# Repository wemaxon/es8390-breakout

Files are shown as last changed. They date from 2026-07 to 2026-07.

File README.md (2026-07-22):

# ES8390 Breakout Board

A KiCad-based ES8390 audio codec breakout board featuring guitar and line inputs, an onboard MEMS microphone, line and amplified stereo speaker outputs.

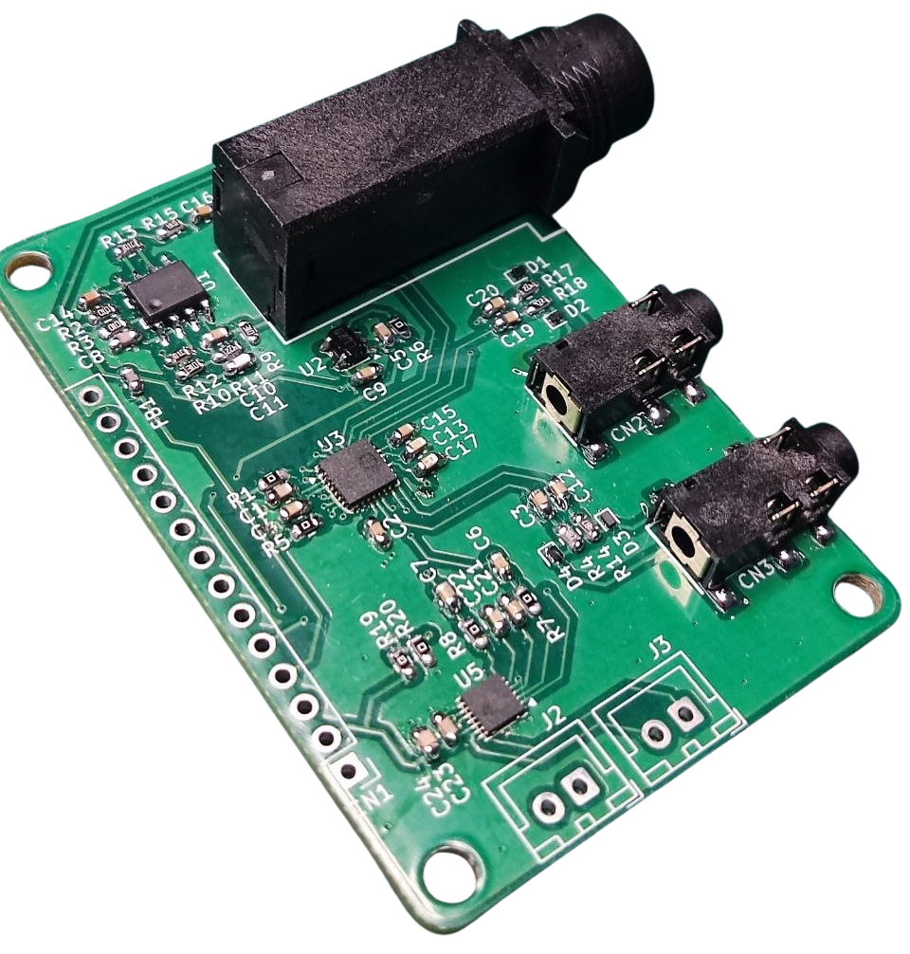
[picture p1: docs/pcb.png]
pcb


Tested Features:
- [x] LP5907 3.0V LDO
- [x] ES8390 Audio-Codec
- [x] Line-Out
- [ ] Line-In
- [x] MAX98306 Class D Stereo Amp
- [ ] TLV9062 Guitar Pre-Amp
- [ ] MSM381ACP003 MEMS Microphone

## Schematic
schematic

## Layout
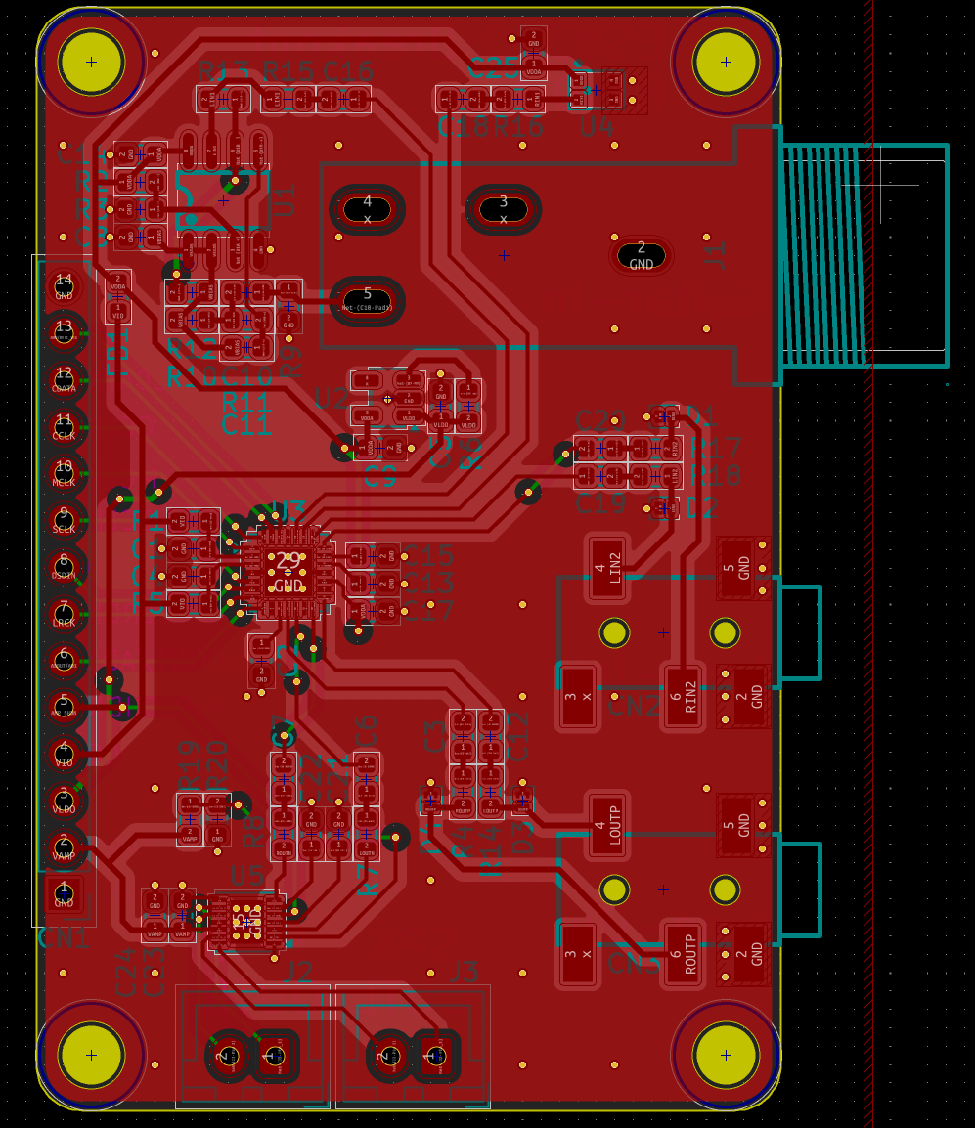
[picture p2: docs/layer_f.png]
layer_f

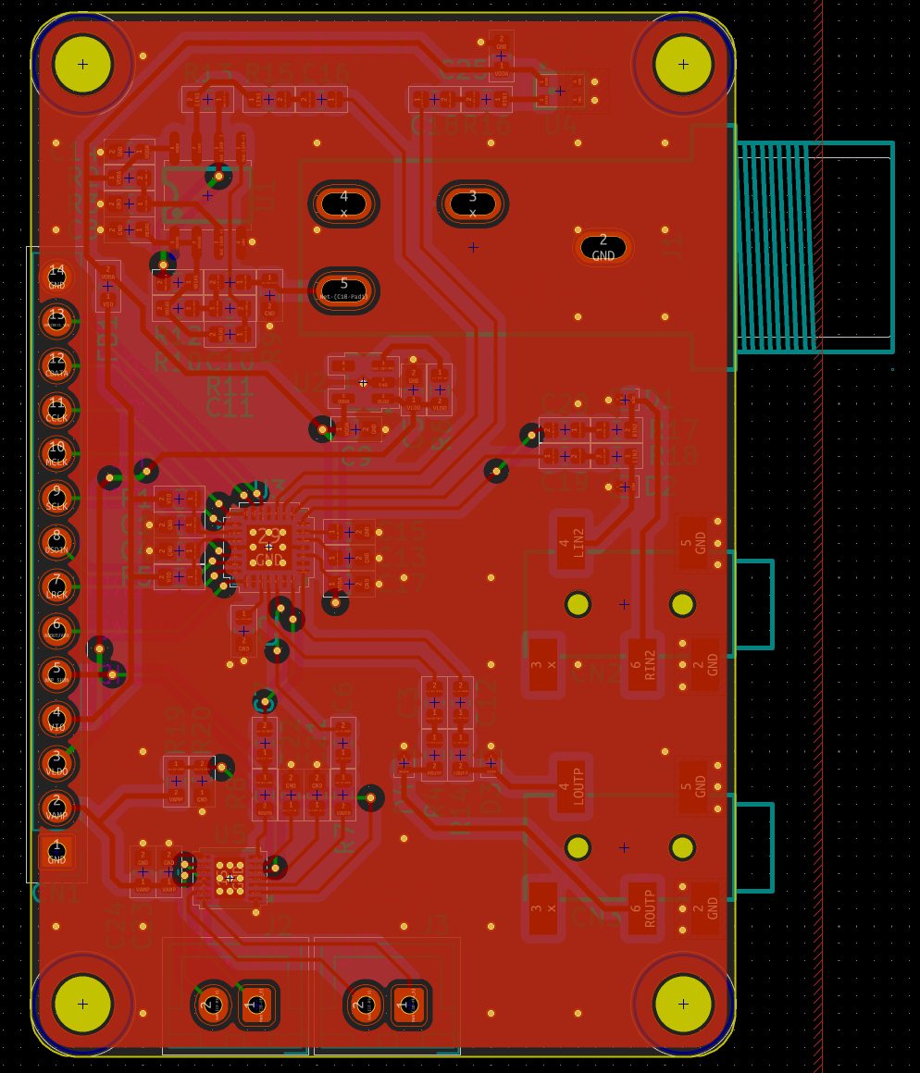
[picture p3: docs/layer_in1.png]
layer_in1

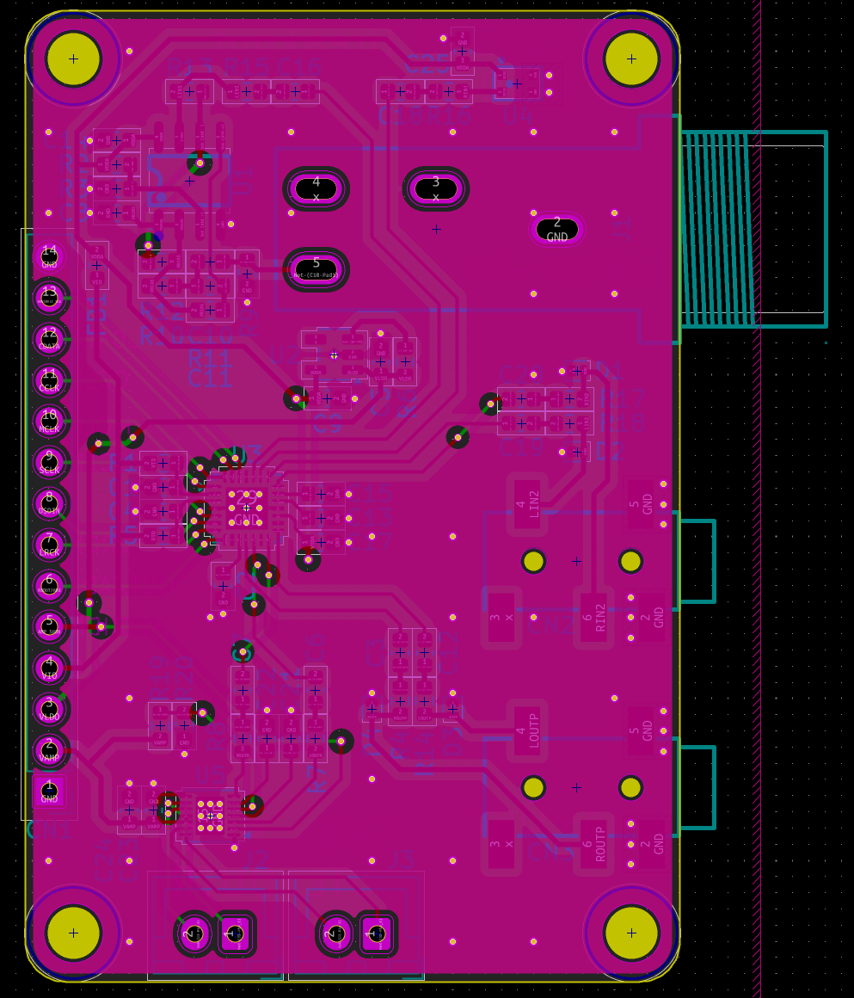
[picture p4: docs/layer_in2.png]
layer_in2

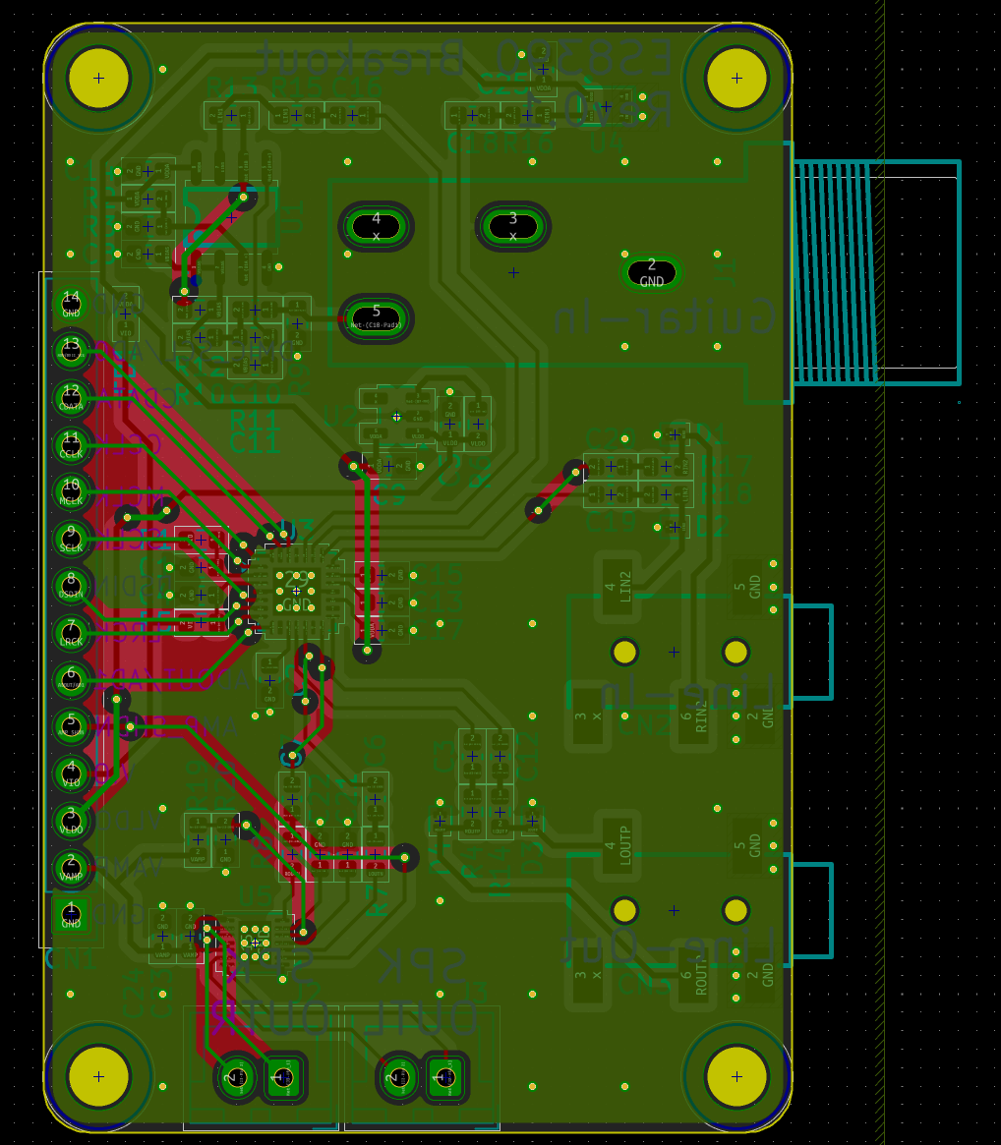
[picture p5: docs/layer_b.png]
layer_b


## Todo
- Fix OUT connections, OUTN to gnd, use output as single ended

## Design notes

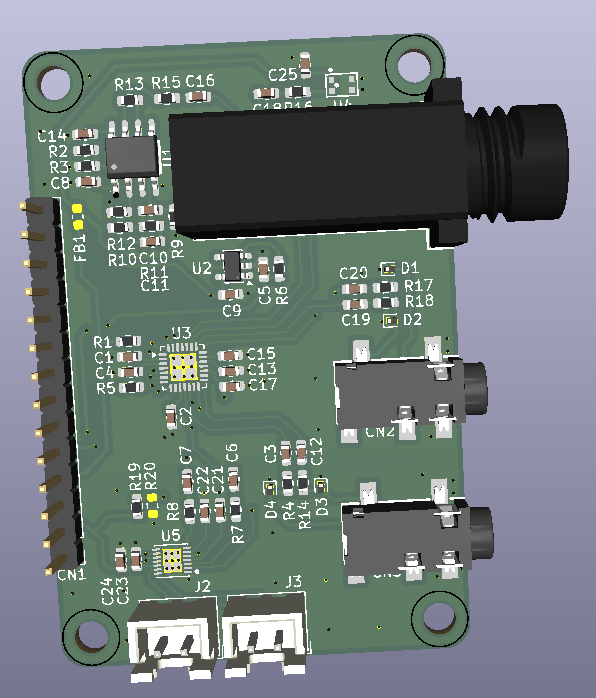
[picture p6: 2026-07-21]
docs/3d.png

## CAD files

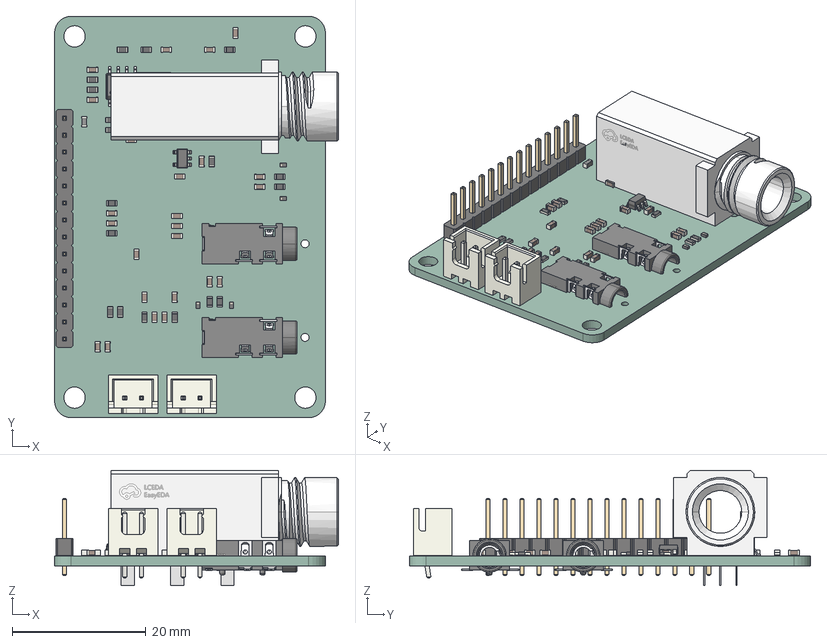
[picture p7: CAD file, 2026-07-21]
es8390-breakout.step
42.5 x 60.0 x 17.2 mm
R_0603_1608Metric x 20
C_0603_1608Metric x 25
JST_XH_B2B-XH-A_1x02_P2.50mm_Vertical x 2
D_SOD-882 x 4
L_0603_1608Metric
AUDIO-SMD_XUNPU_PJ-327A x 2
PinHeader_1x14_P2.54mm_Vertical
SOIC-8_L5.0-W4.0-P1.27-LS6.0-BL
AUDIO-SMD_PJ-603A
SOT-23-5
ES8390-breakout_PCB

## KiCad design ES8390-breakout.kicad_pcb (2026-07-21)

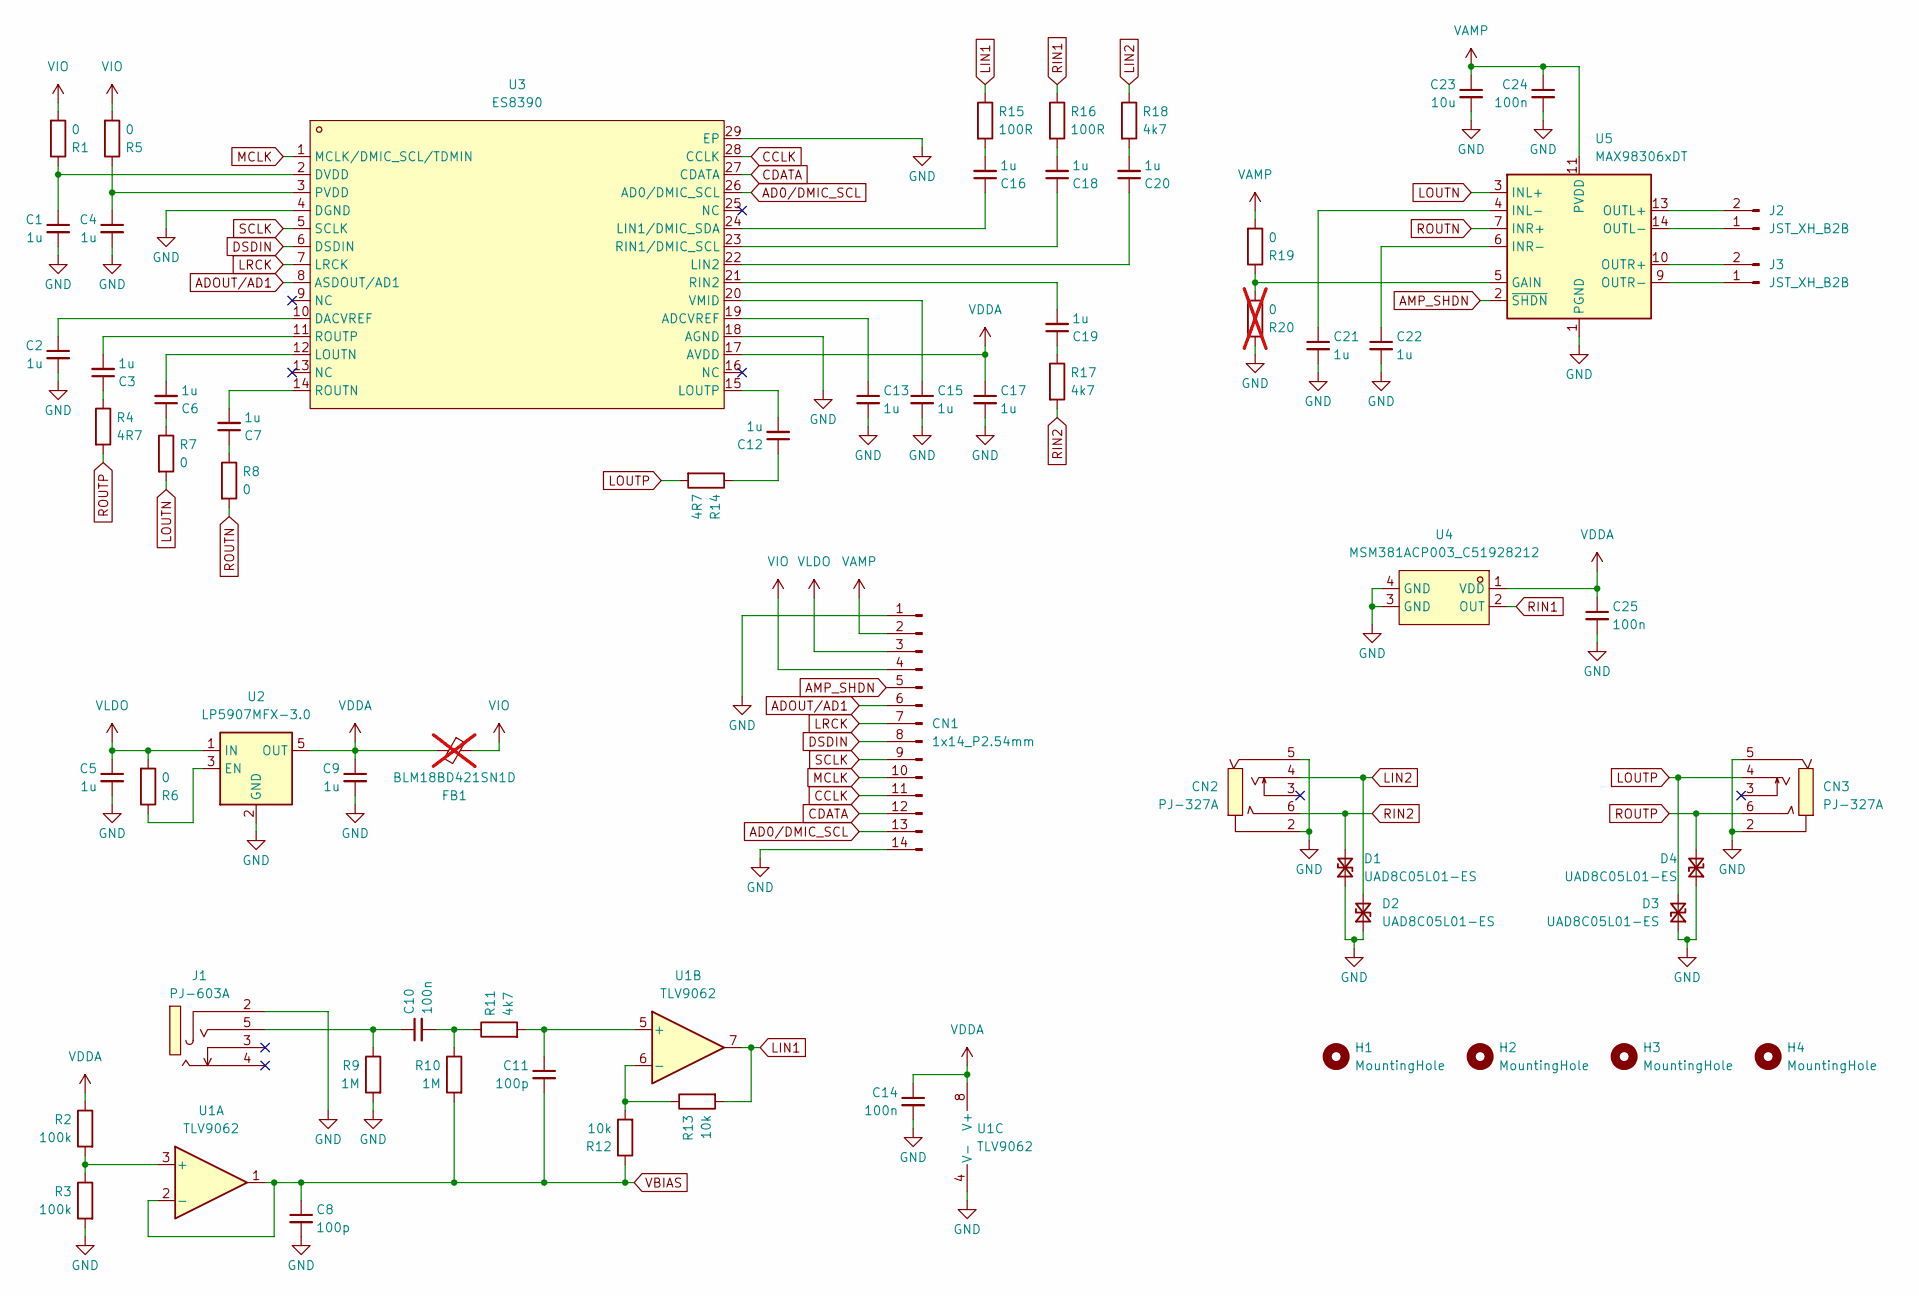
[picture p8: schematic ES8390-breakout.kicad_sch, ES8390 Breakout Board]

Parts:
C1, C2, C3, C4, C5, C6, C7, C9, C12, C13, C15, C16, C17, C18, C19, C20, C21, C22: 1u; C_0603_1608Metric; LCSC Part C15849
C8, C11: 100p; C_0603_1608Metric; LCSC Part C14663
C10, C14, C24, C25: 100n; C_0603_1608Metric; LCSC Part C14663
C23: 10u; C_0603_1608Metric; LCSC Part C96446
CN1: 1x14_P2.54mm; PinHeader_1x14_P2.54mm_Vertical
CN2, CN3: PJ-327A; AUDIO-SMD_XUNPU_PJ-327A; MPN PJ-327A; LCSC Part C49284723
D1, D2, D3, D4: UAD8C05L01-ES; D_SOD-882; LCSC Part C5199205
FB1: BLM18BD421SN1D; L_0603_1608Metric; LCSC Part C113023; not fitted
H1, H2, H3, H4: MountingHole; MountingHole_3.2mm_M3_DIN965
J1: PJ-603A; AUDIO-TH_PJ-603A; MPN PJ-603A; LCSC Part C309273
J2, J3: JST_XH_B2B; JST_XH_B2B-XH-A_1x02_P2.50mm_Vertical
R1, R5, R6, R7, R8, R19: 0; R_0603_1608Metric; LCSC Part C95177
R2, R3: 100k; R_0603_1608Metric; LCSC Part C14675
R4, R14: 4R7; R_0603_1608Metric; LCSC Part C105588
R9, R10: 1M; R_0603_1608Metric; LCSC Part C105578
R11, R17, R18: 4k7; R_0603_1608Metric; LCSC Part C99782
R12, R13: 10k; R_0603_1608Metric; LCSC Part C2906982
R15, R16: 100R; R_0603_1608Metric; LCSC Part C105588
R20: 0; R_0603_1608Metric; LCSC Part C95177; not fitted
U1: TLV9062; SOIC-8_L5.0-W4.0-P1.27-LS6.0-BL; LCSC Part C54539963
U2: LP5907MFX-3.0; SOT-23-5; LCSC Part C23380873
U3: ES8390; QFN-28-1EP_4x4mm_P0.45mm_EP2.6x2.6mm; MPN ES8390; LCSC Part C42405905
U4: MSM381ACP003_C51928212; MIC-SMD_4P-L2.8-W1.9-TR_MSM381ACP003; MPN MSM381ACP003; LCSC Part C51928212
U5: MAX98306xDT; TDFN-14-1EP_3x3mm_P0.4mm_EP1.78x2.35mm; LCSC Part C124549

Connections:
AD0/DMIC_SCL: CN1.13, U3.26 (AD0/DMIC_SCL)
ADOUT/AD1: CN1.6, U3.8 (ASDOUT/AD1)
AMP_SHDN: CN1.5, U5.2 (~SHDN)
CCLK: CN1.11, U3.28 (CCLK)
CDATA: CN1.12, U3.27 (CDATA)
DSDIN: CN1.8, U3.6 (DSDIN)
GND: C1.2, C2.2, C4.2, C5.2, C8.2, C9.2, C13.2, C14.2, C15.2, C17.2, C21.2, C22.2, C23.2, C24.2, C25.2, CN1.1, CN1.14, CN2.2, CN2.5, CN3.2, CN3.5, D1.1 (A1), D2.1 (A1), D3.1 (A1), D4.1 (A1), J1.2, R3.2, R9.2, R20.1, U1.4 (V-), U2.2 (GND), U3.4 (DGND), U3.18 (AGND), U3.29 (EP), U4.3 (GND), U4.4 (GND), U5.1 (PGND), U5.8 (PGND), U5.15 (PGND)
LIN1: R13.2, R15.1, U1.7
LIN2: CN2.4, D2.2 (A2), R18.1
LOUTN: R7.2, U5.3 (INL+)
LOUTP: CN3.4, D3.2 (A2), R14.2
LRCK: CN1.7, U3.7 (LRCK)
MCLK: CN1.10, U3.1 (MCLK/DMIC_SCL/TDMIN)
unnamed: C3.1, R4.1
unnamed: C6.1, R7.1
unnamed: C7.1, R8.1
unnamed: C10.1, J1.5, R9.1
unnamed: C10.2, R10.1, R11.1
unnamed: C12.1, R14.1
unnamed: C16.2, R15.2
unnamed: C18.2, R16.2
unnamed: C19.1, R17.1
unnamed: C20.2, R18.2
unnamed: J2.1, U5.14 (OUTL-)
unnamed: J2.2, U5.13 (OUTL+)
unnamed: J3.1, U5.9 (OUTR-)
unnamed: J3.2, U5.10 (OUTR+)
unnamed: R2.2, R3.1, U1.3 (+)
unnamed: C11.1, R11.2, U1.5 (+)
unnamed: R12.2, R13.1, U1.6 (-)
unnamed: R6.1, U2.3 (EN)
unnamed: C13.1, U3.19 (ADCVREF)
unnamed: C2.1, U3.10 (DACVREF)
unnamed: C1.1, R1.1, U3.2 (DVDD)
unnamed: C16.1, U3.24 (LIN1/DMIC_SDA)
unnamed: C20.1, U3.22 (LIN2)
unnamed: C6.2, U3.12 (LOUTN)
unnamed: C12.2, U3.15 (LOUTP)
unnamed: C4.1, R5.1, U3.3 (PVDD)
unnamed: C18.1, U3.23 (RIN1/DMIC_SCL)
unnamed: C19.2, U3.21 (RIN2)
unnamed: C7.2, U3.14 (ROUTN)
unnamed: C3.2, U3.11 (ROUTP)
unnamed: C15.1, U3.20 (VMID)
unnamed: R19.1, R20.2, U5.5 (GAIN)
unnamed: C21.1, U5.4 (INL-)
unnamed: C22.1, U5.6 (INR-)
RIN1: R16.1, U4.2 (OUT)
RIN2: CN2.6, D1.2 (A2), R17.2
ROUTN: R8.2, U5.7 (INR+)
ROUTP: CN3.6, D4.2 (A2), R4.2
SCLK: CN1.9, U3.5 (SCLK)
VAMP: C23.1, C24.1, CN1.2, R19.2, U5.11 (PVDD), U5.12 (PVDD)
VBIAS: C8.1, C11.2, R10.2, R12.1, U1.1, U1.2 (-)
VDDA: C9.1, C14.1, C17.1, C25.1, FB1.2, R2.1, U1.8 (V+), U2.5 (OUT), U3.17 (AVDD), U4.1 (VDD)
VIO: CN1.4, FB1.1, R1.2, R5.2
VLDO: C5.1, CN1.3, R6.2, U2.1 (IN)

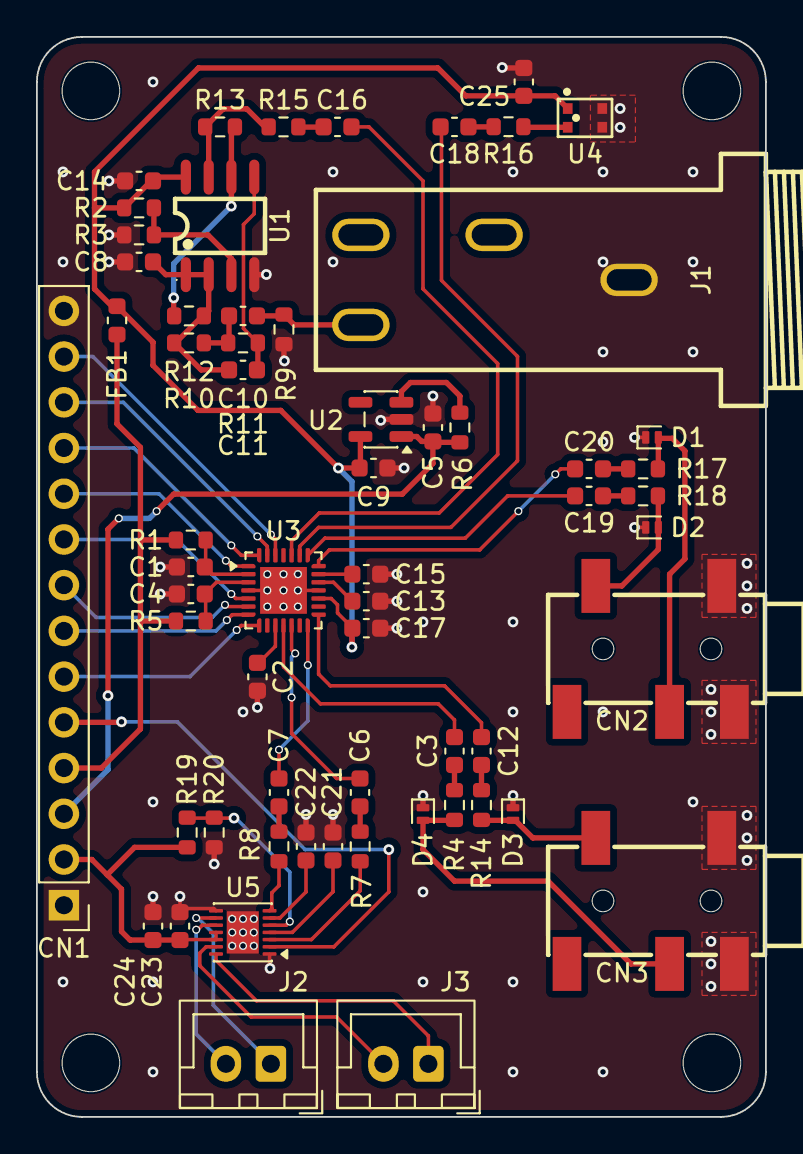
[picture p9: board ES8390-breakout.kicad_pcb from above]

Board: 4 copper layers, 40.5 x 60.0 mm, 65 parts (0 on the bottom side), 57 nets.

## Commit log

2026-05-11 add lcsc symbols, footprints, models
2026-05-11 schematics done?
    [ES8390-breakout.kicad_sch]
2026-05-11 lib cleanup, start schematic
    [ES8390-breakout.kicad_pcb, ES8390-breakout.kicad_sch]
2026-05-11 guitar input stage?
    [ES8390-breakout.kicad_pcb, ES8390-breakout.kicad_sch]
2026-05-12 guitar input stage schematic
    [ES8390-breakout.kicad_sch]
2026-05-12 add ESD
    [ES8390-breakout.kicad_sch]
2026-05-14 fix guitar input stage
    [ES8390-breakout.kicad_sch]
2026-05-14 add lcsc parts, ts-mono jack
    [ES8390-breakout.kicad_pcb, ES8390-breakout.kicad_sch]
2026-05-15 continue layout
    [ES8390-breakout.kicad_pcb]
2026-05-18 first layout done
    [ES8390-breakout.kicad_pcb, ES8390-breakout.kicad_sch]
2026-05-18 fix lcsc audio footprints
    [ES8390-breakout.kicad_pcb]
2026-05-18 via stitching 5mm
    [ES8390-breakout.kicad_pcb]
2026-05-18 replace microphone with top port MEMS MSM381ACP003
    [ES8390-breakout.kicad_pcb, ES8390-breakout.kicad_sch]
2026-05-18 replace microphone with top port MEMS MSM381ACP003, save pcb
    [ES8390-breakout.kicad_pcb]
2026-05-18 add silkscreen
    [ES8390-breakout.kicad_pcb]
2026-05-18 generate gerbers
    [ES8390-breakout-B_Cu.gbr, ES8390-breakout-B_Mask.gbr, ES8390-breakout-B_Paste.gbr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]
2026-05-19 v0.1 ordered pcb and components
    [ES8390-breakout-B_Cu.gbr, ES8390-breakout-B_Mask.gbr, ES8390-breakout-B_Paste.gbr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]
2026-07-21 fix silkscreen layout
    [ES8390-breakout.kicad_pcb]
2026-07-21 Add step 3d model
    [es8390-breakout.step]
2026-07-21 add bom export path to project
2026-07-22 add pcb image
